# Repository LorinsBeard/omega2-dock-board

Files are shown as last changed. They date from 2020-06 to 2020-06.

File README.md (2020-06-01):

# Omega2 Dock board

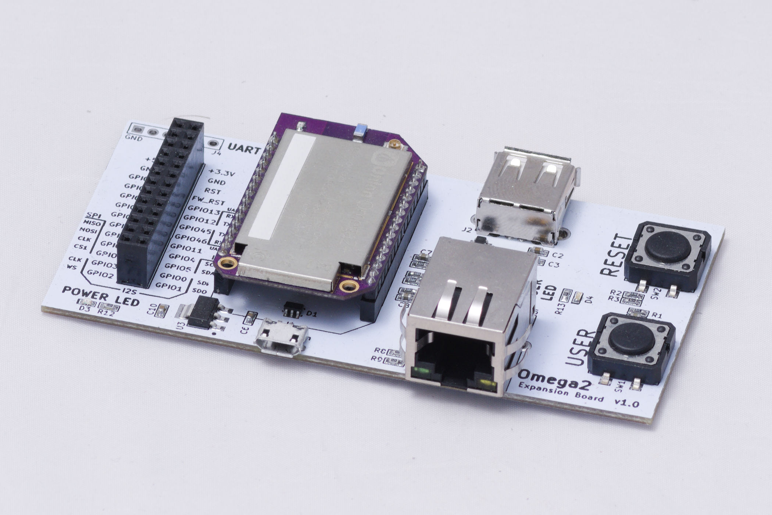
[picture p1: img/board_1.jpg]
Omega board photo 1


Inspired by [Omega dock\new](https://github.com/5N44P/omega-dock-new) board.

## Overview

This is yet another dock for Onion Omega2/Omega2+ single board computers. 
Main board features:

* Ethernet socket
* USB type A Host
* Micro USB power and UART
* Expansion pins
* User Button and LED

## BOM

BOM is also available in CSV format.

| Reference | Quantity | Description | MPN | Manufacturer | Datasheet |
|---|---:|---|-----|---|---|
| C10 C2  | 2 | CAP CER 10UF 6.3V X5R 0603 | CL10A106MQ8NNNC | Samsung Electro-Mechanics | [link](http://www.samsungsem.com/kr/support/product-search/mlcc/__icsFiles/afieldfile/2018/06/20/CL10A106MQ8NNNC.pdf) |
| C4 C5  | 2 | CAP CER 22pF 50V NPO 0603 | CL10C220JB8NNN | Samsung Electro-Mechanics | [link](www.samsungsem.com/global/front/downloadcms.do?path=%2F%2Fglobal%2F%2Fsupport%2F%2Fproduct-search%2F%2Fmlcc%2F%2F__icsFiles%2F%2Fafieldfile%2F%2F2016%2F%2F08%2F%2F18&fileName=S_CL10C220JB8NNNL.pdf) |
| C6 C8 C7 C1 C3  | 5 | CAP CER 0.1UF 50V X7R 0603 | CL10B104KB8NNNC | Samsung Electro-Mechanics | [link](http://www.samsungsem.com/kr/support/product-search/mlcc/__icsFiles/afieldfile/2018/07/24/CL10B104KB8NNNC.pdf) |
| C9  | 1 | CAP CER 1UF 16V X7R 0603 | CL10B105KO8NNNC | Samsung Electro-Mechanics | [link](http://www.samsungsem.com/kr/support/product-search/mlcc/__icsFiles/afieldfile/2019/06/18/CL10B105KO8NNNC-19.pdf) |
| D2 D1  | 2 | TVS DIODE 5.25V 17V SOT23-6 | USBLC6-2SC6 | STMicroelectronics | [link](http://www.st.com/content/ccc/resource/technical/document/datasheet/06/1d/48/9c/6c/20/4a/b2/CD00050750.pdf/files/CD00050750.pdf/jcr:content/translations/en.CD0005075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) |
| D3 D4  | 2 | LED Yellow Green 0603 30mA | FYLS-0603GD | FORYARD OPTOELECTRONICS | [link](http://www.foryard-led.ru/pdf/fyls-0603gd.pdf) |
| F1  | 1 | PTC RESET FUSE 6V 1.1A 1206 | MF-NSMF110-2 | Bourns | [link](https://www.bourns.com/docs/Product-Datasheets/mfnsmf.pdf) |
| J1  | 1 | CONN RCPT USB2.0 MICRO B SMD R/A | 10118194-0001LF | Amphenol ICC (FCI) | [link](http://www.amphenol-icc.com/media/wysiwyg/files/drawing/10118194.pdf) |
| J2  | 1 | CONN RCPT USB2.0 TYPEA 4POS R/A | KLS1-181A-W | KLS | [link](http://www.klsele.com/admin/product_upload/20190917081512KLS1-1811%20A%20Female%20Dip%2090%20USB%20Connector%202.jpg.pdf) |
| J3  | 1 | CONN F HEADER 26POS 2.54mm | ZL262-26DG | CONNFLY | [link](http://www.kosmodrom.com.ua/pdf/zl262-dg.pdf) |
| J4  | 1 | CONN M HEADER 6 POS 2.54mm | ZL201-06G | CONNFLY | [link](http://www.kosmodrom.com.ua/pdf/zl201.pdf) |
| J5  | 1 | RJ45 connector with transformer | KLS12-TL002R-1*1-G/Y-1-03 | KLS | [link](http://www.klsele.com/admin/product_upload/20170620132005KLS12-TL002-1X1.pdf) |
| R1 R3  | 2 | SMD RES 0603 10 kOhm 100mW 50V | RC0603FR-10KR | Hitano | [link](https://www.rcscomponents.kiev.ua/datasheets/komechip-eesistor-datasheet.pdf) |
| R11 R7 R6 R10  | 4 | SMD RES 0603 49.9 Ohm 100mW 50V | RC0603FR-49R9 | Hitano | [link](https://www.rcscomponents.kiev.ua/datasheets/rc_series_hitano-datasheet.pdf) |
| R12 R4 R5 R8 R9 R2 R13  | 7 | SMD RES 0603 470 Ohm 100mW 50V | RC0603JR-470R | Hitano | [link](https://www.rcscomponents.kiev.ua/datasheets/rc_series_hitano-datasheet.pdf) |
| SW2 SW1  | 2 | SWITCH TACTILE SPST-NO 0.05A 12V | TACTM-24N-F | NINIGI | [link](https://en.ninigi.com/product/tactm-24n-f/pdf) |
| U1  | 1 | USB UART CONVERTER 16SOIC | CH340G | WCH | [link](www.datasheet5.com/pdf-local-2195953) |
| U2  | 1 | SBC  | Omega2 | Onion | [link](https://docs.onion.io/omega2-docs/omega2p.html) |
| U3  | 1 | IC REG LINEAR 3.3V 800MA SOT223  | LD1117S33TR | STMicroelectronics | [link](https://www.st.com/content/ccc/resource/technical/document/datasheet/99/3b/7d/91/91/51/4b/be/CD00000544.pdf/files/CD00000544.pdf/jcr:content/translations/en.CD000005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) |
| Y1  | 1 | Quartz Crystal SMD 12.0 MHz | 12.88662 | GEYER | [link](https://www.geyer-electronic.com/fileadmin/user_upload/frequenz/quartz/KX-7/GEYER-KX-7.pdf) |

Note:

I have bought a KLS Ethernet connector for **J5** but used a footprint for [Amphenol ICC RJMG1BD3B8K1ANR](https://www.digikey.com/product-detail/en/amphenol-icc-commercial-products/RJMG1BD3B8K1ANR/RJMG1BD3B8K1ANR-ND/5359794) connector. There is just one difference - **reversed pinout** for Yellow LED. 

Also, I have bought a KLS USB A connector for **J2** and used an [Amphenol ICC UE27AC54100](https://www.digikey.com/product-detail/en/amphenol-icc-commercial-products/UE27AC54100/UE27AC54100-ND) footprint, but they are similar, though.

## Schematic & PCB

Designed using **KiCAD**. Also, I have take some parts from [Digi-Key Kicad library](https://www.digikey.com/en/resources/design-tools/kicad). 

The library with footprints is available at the project directory [omega-dock](./omega-dock).

Board has user **Button** at **GPIO11** and **LED** at **GPIO17**. To able these ones just solder bridges **SB1** and **SB4**.

Also, to able Ethernet LEDs solder bridges **SB2** and **SB3**.

## Known bugs

I have realized that there is no fuse for a USB power socket and it may cause damage to the USB port on your PC. So, it recommends using USB 3.0 and higher.

## Other photos

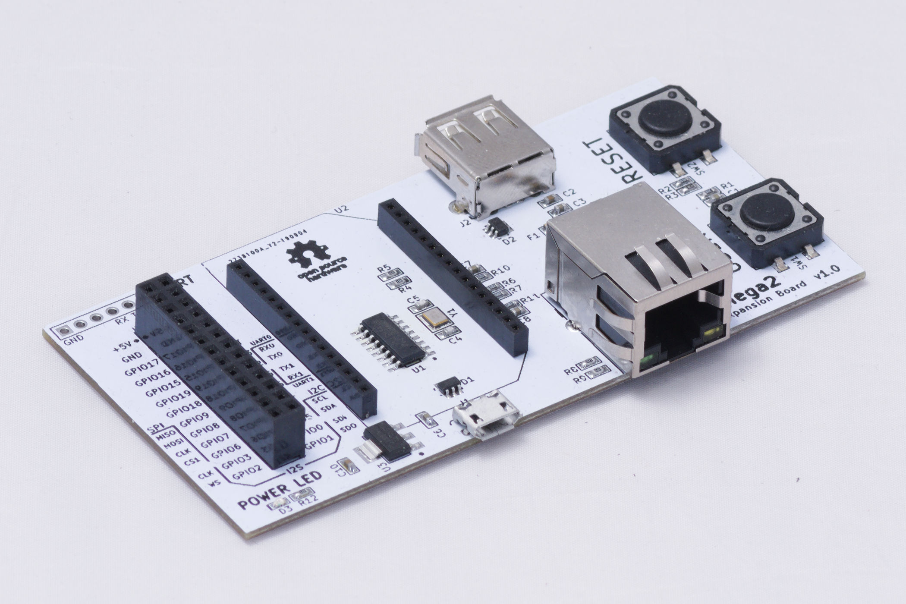
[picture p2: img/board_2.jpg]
Omega board photo 2

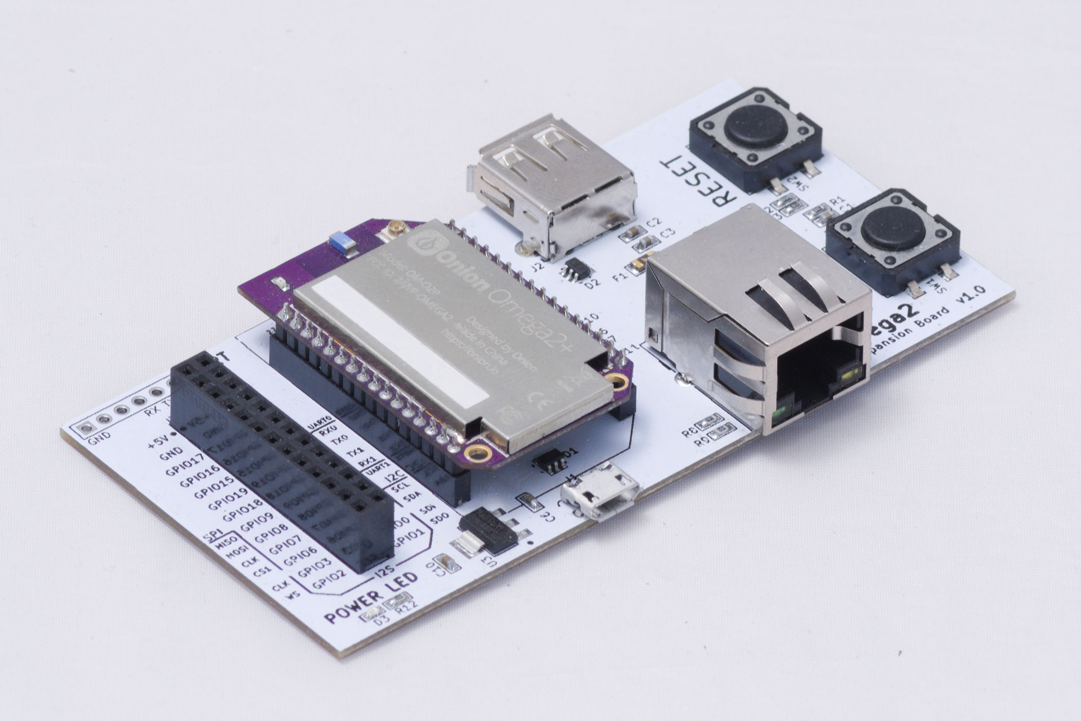
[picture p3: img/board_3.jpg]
Omega board photo 3


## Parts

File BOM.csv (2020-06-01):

Reference | Quantity | Description | MPN | Manufacturer | Datasheet
C10 C2 | 2 | CAP CER 10UF 6.3V X5R 0603 | CL10A106MQ8NNNC | Samsung Electro-Mechanics | http://www.samsungsem.com/kr/support/product-search/mlcc/__icsFiles/afieldfile/2018/06/20/CL10A106MQ8NNNC.pdf
C4 C5 | 2 | CAP CER 22pF 50V NPO 0603 | CL10C220JB8NNN | Samsung Electro-Mechanics | www.samsungsem.com/global/front/downloadcms.do?fileName=S_CL10C220JB8NNNL.pdf
C6 C8 C7 C1 C3 | 5 | CAP CER 0.1UF 50V X7R 0603 | CL10B104KB8NNNC | Samsung Electro-Mechanics | http://www.samsungsem.com/kr/support/product-search/mlcc/__icsFiles/afieldfile/2018/07/24/CL10B104KB8NNNC.pdf
C9 | 1 | CAP CER 1UF 16V X7R 0603 | CL10B105KO8NNNC | Samsung Electro-Mechanics | http://www.samsungsem.com/kr/support/product-search/mlcc/__icsFiles/afieldfile/2019/06/18/CL10B105KO8NNNC-19.pdf
D2 D1 | 2 | TVS DIODE 5.25V 17V SOT23-6 | USBLC6-2SC6 | STMicroelectronics | http://www.st.com/content/ccc/resource/technical/document/datasheet/06/1d/48/9c/6c/20/4a/b2/CD00050750.pdf/files/CD00050750.pdf/jcr:content/translations/en.CD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
D3 D4 | 2 | LED Yellow Green 0603 30mA | FYLS-0603GD | FORYARD OPTOELECTRONICS | http://www.foryard-led.ru/pdf/fyls-0603gd.pdf
F1 | 1 | PTC RESET FUSE 6V 1.1A 1206 | MF-NSMF110-2 | Bourns | https://www.bourns.com/docs/Product-Datasheets/mfnsmf.pdf
J1 | 1 | CONN RCPT USB2.0 MICRO B SMD R/A | 10118194-0001LF | Amphenol ICC (FCI) | http://www.amphenol-icc.com/media/wysiwyg/files/drawing/10118194.pdf
J2 | 1 | CONN RCPT USB2.0 TYPEA 4POS R/A | KLS1-181A-W | KLS | http://www.klsele.com/admin/product_upload/20190917081512KLS1-1811%20A%20Female%20Dip%2090%20USB%20Connector%202.jpg.pdf
J3 | 1 | CONN F HEADER 26POS 2.54mm | ZL262-26DG | CONNFLY | http://www.kosmodrom.com.ua/pdf/zl262-dg.pdf
J4 | 1 | CONN M HEADER 6 POS 2.54mm | ZL201-06G | CONNFLY | http://www.kosmodrom.com.ua/pdf/zl201.pdf
J5 | 1 | RJ45 connector with transformer | KLS12-TL002R-1*1-G/Y-1-03 | KLS | http://www.klsele.com/admin/product_upload/20170620132005KLS12-TL002-1X1.pdf
R1 R3 | 2 | SMD RES 0603 10 kOhm 100mW 50V | RC0603FR-10KR | Hitano | https://www.rcscomponents.kiev.ua/datasheets/komechip-eesistor-datasheet.pdf
R11 R7 R6 R10 | 4 | SMD RES 0603 49.9 Ohm 100mW 50V | RC0603FR-49R9 | Hitano | https://www.rcscomponents.kiev.ua/datasheets/rc_series_hitano-datasheet.pdf
R12 R4 R5 R8 R9 R2 R13 | 7 | SMD RES 0603 470 Ohm 100mW 50V | RC0603JR-470R | Hitano | https://www.rcscomponents.kiev.ua/datasheets/rc_series_hitano-datasheet.pdf
SW2 SW1 | 2 | SWITCH TACTILE SPST-NO 0.05A 12V | TACTM-24N-F | NINIGI | https://en.ninigi.com/product/tactm-24n-f/pdf
U1 | 1 | USB UART CONVERTER 16SOIC | CH340G | WCH | www.datasheet5.com/pdf-local-2195953
U2 | 1 | SBC | Omega2 | Onion | https://docs.onion.io/omega2-docs/omega2p.html
U3 | 1 | IC REG LINEAR 3.3V 800MA SOT223 | LD1117S33TR | STMicroelectronics | https://www.st.com/content/ccc/resource/technical/document/datasheet/99/3b/7d/91/91/51/4b/be/CD00000544.pdf/files/CD00000544.pdf/jcr:content/translations/en.C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
Y1 | 1 | Quartz Crystal SMD 12.0 MHz | 12.88662 | GEYER | https://www.geyer-electronic.com/fileadmin/user_upload/frequenz/quartz/KX-7/GEYER-KX-7.pdf

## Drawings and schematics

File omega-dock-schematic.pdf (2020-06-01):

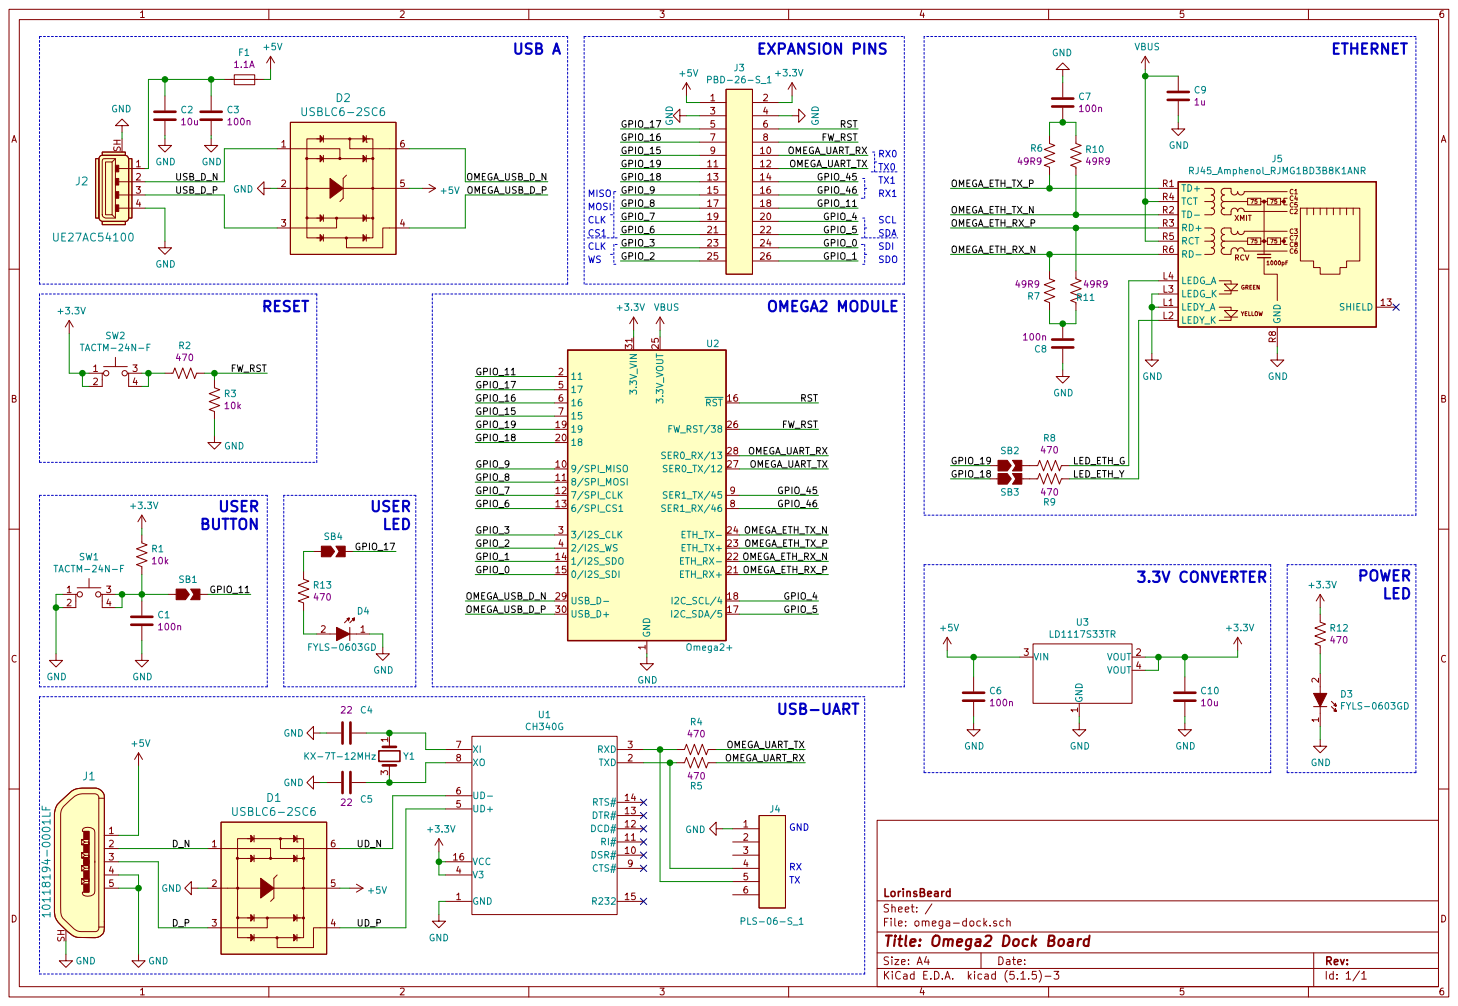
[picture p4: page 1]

File: omega-dock.sch Sheet: / LorinsBeard

Id: 1/1 Title: Omega2 Dock Board

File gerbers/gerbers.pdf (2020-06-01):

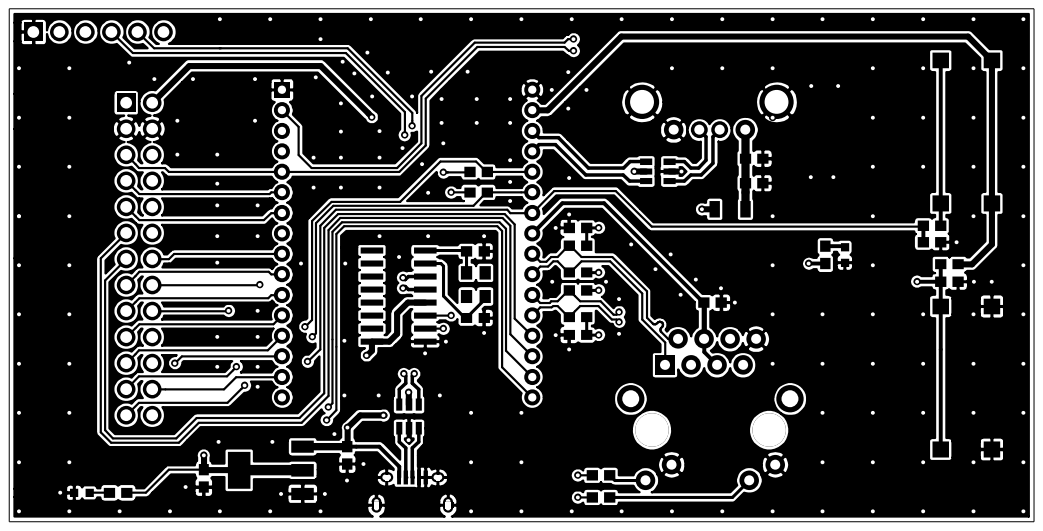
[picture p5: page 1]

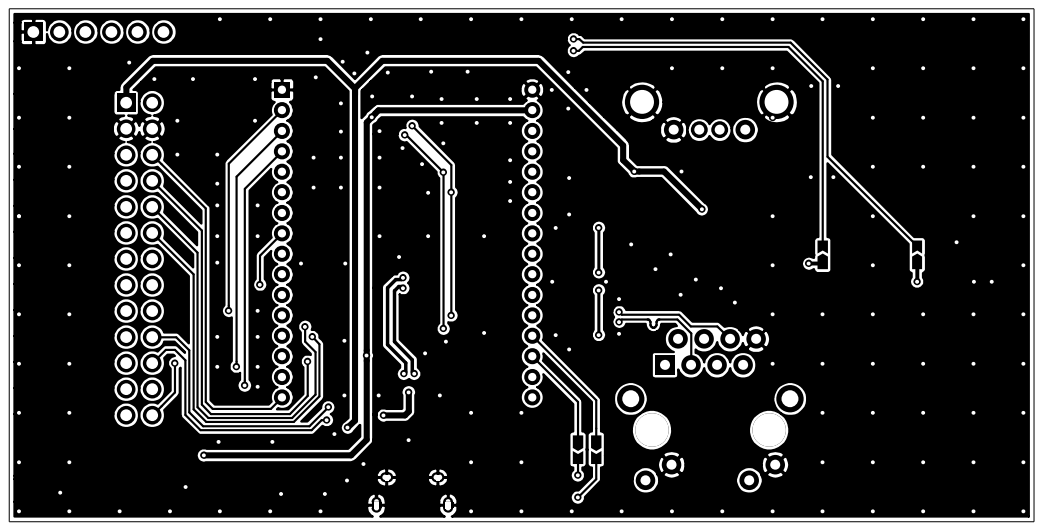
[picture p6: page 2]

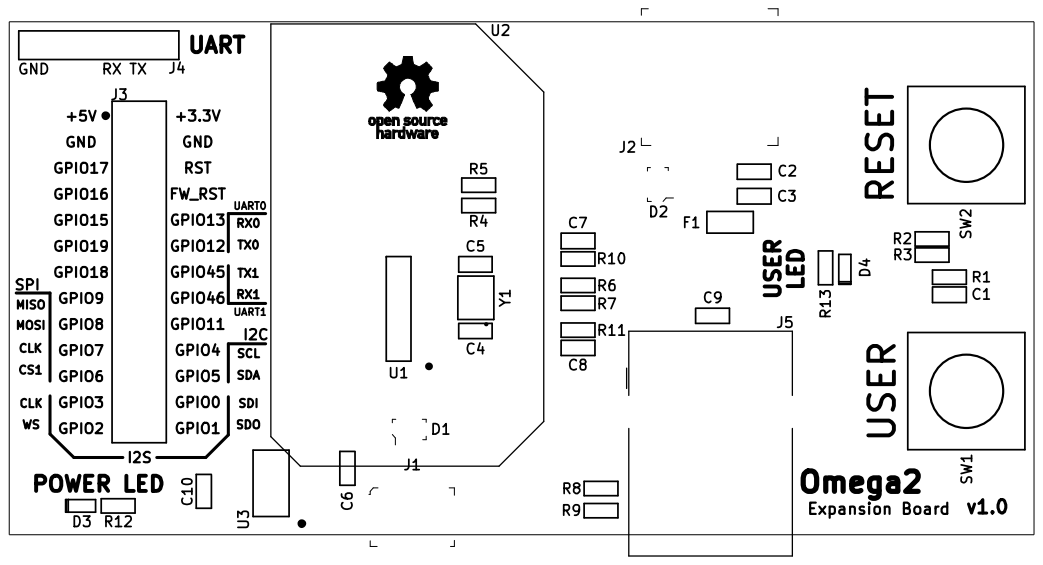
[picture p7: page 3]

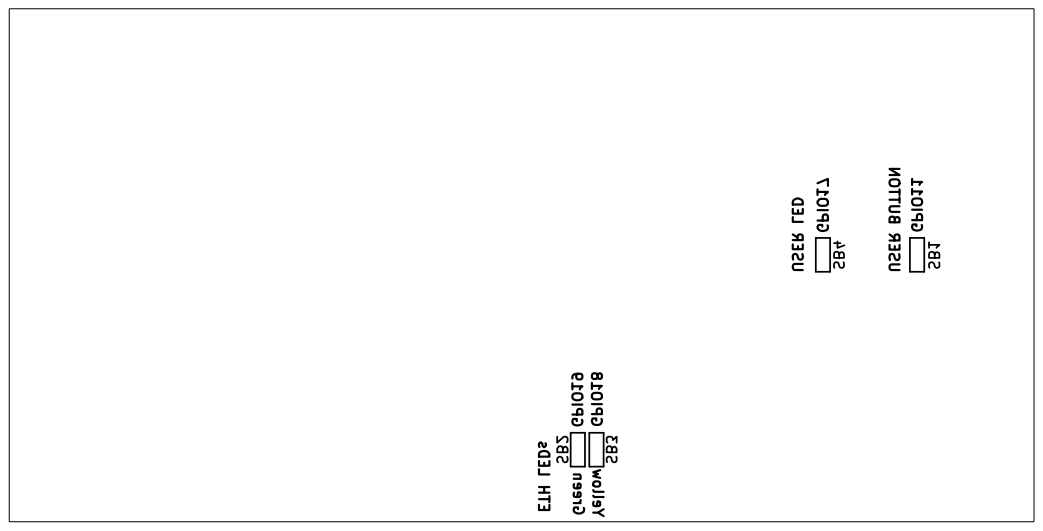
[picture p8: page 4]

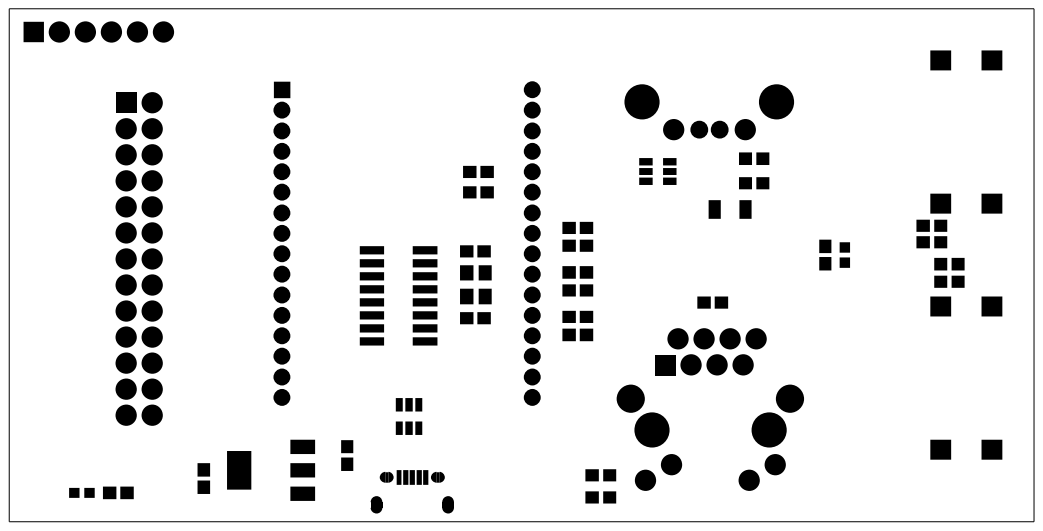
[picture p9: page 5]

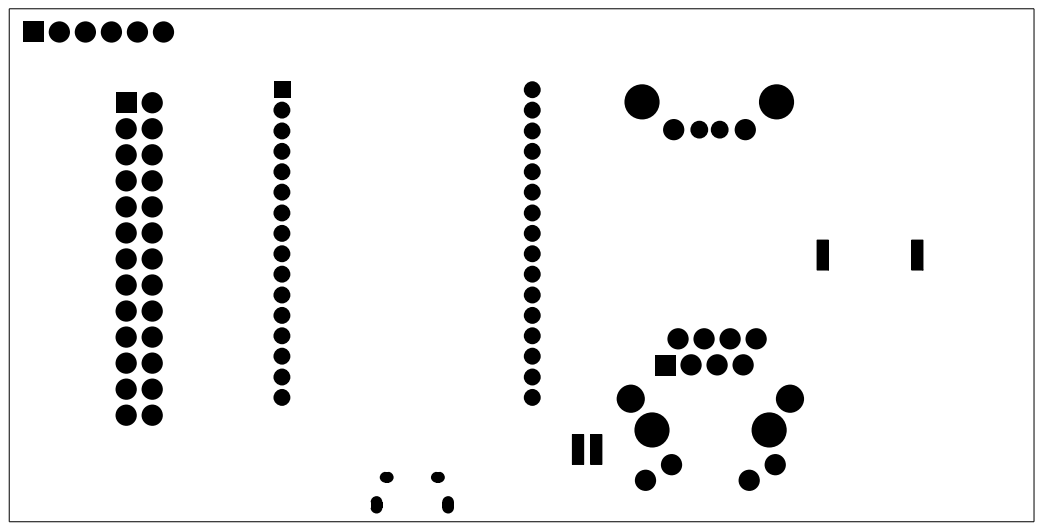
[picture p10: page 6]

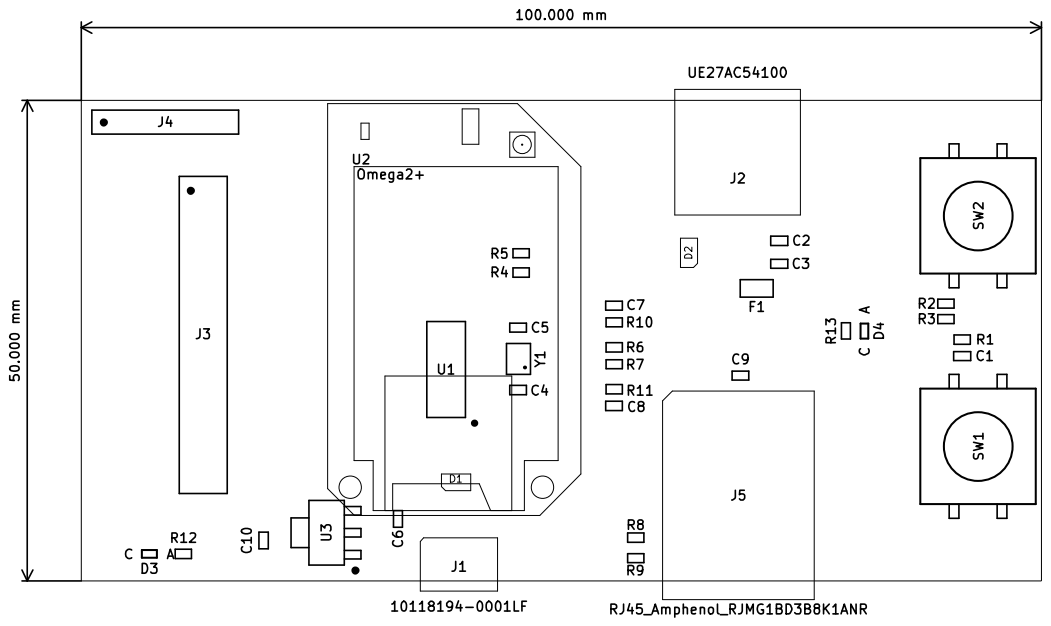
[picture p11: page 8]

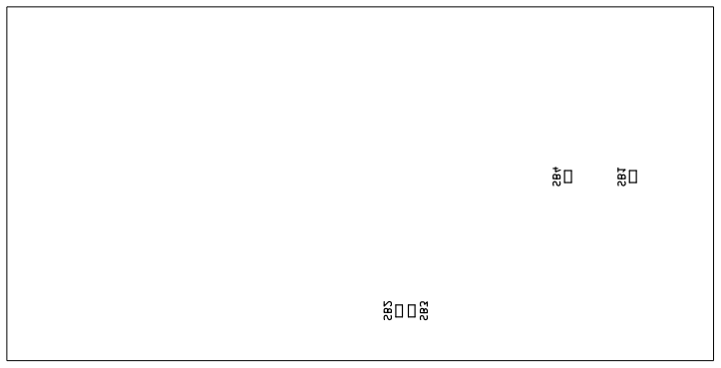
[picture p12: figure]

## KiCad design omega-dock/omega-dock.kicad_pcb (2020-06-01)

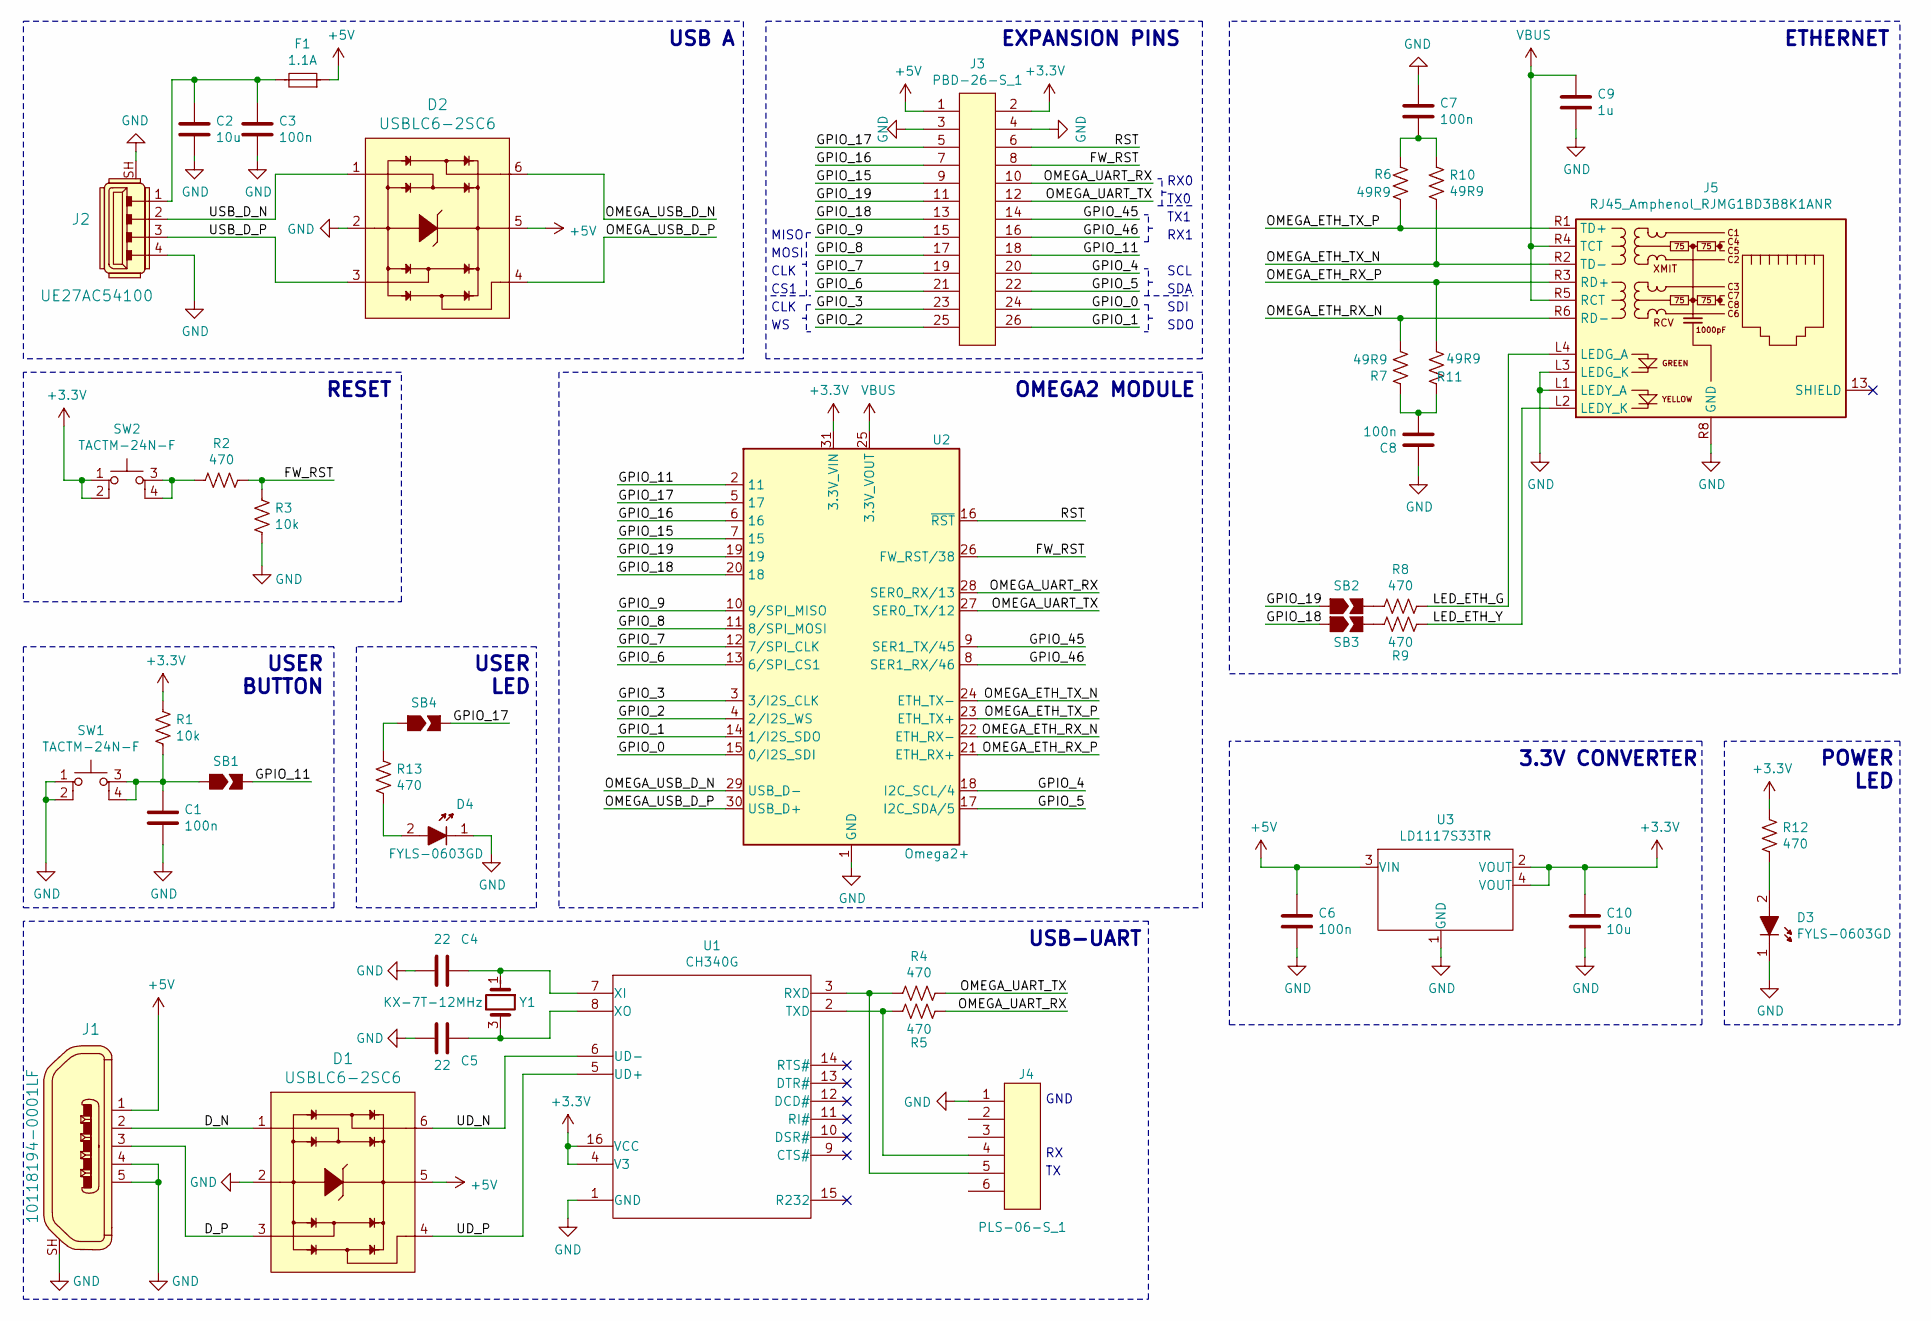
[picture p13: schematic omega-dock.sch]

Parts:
C1, C3, C6, C7, C8: 100n_0603_1; C_0603; MPN CL10B104KB8NNNC
C2, C10: 10u_0603_1; C_0603; MPN CL10A106MQ8NNNC
C4, C5: 22p_0603_1; C_0603; MPN CL10C220JB8NNN
C9: 1u_0603_1; C_0603; MPN CL10B105KO8NNNC
D1, D2: USBLC6-2SC6; SOT23-6L; MPN USBLC6-2SC6; Digi-Key_PN 497-5235-1-ND
D3, D4: FYLS-0603GD; LED_0603_1; MPN FYLS-0603GD
F1: MF-NSMF110; Fuse_BOURNS_MF-NSMF; MPN MF-NSMF110-2
J1: 10118194-0001LF; USB_Micro_B_Female_10118194-0001LF; MPN 10118194-0001LF; Digi-Key_PN 609-4618-1-ND
J2: UE27AC54100; USB_A_Female_UE27AC54100; MPN UE27AC54100; Digi-Key_PN UE27AC54100-ND
J3: PBD-26-S_1; MPN ZL262-26DG
J4: PLS-06-S_1; MPN ZL201-06G
J5: RJ45_Amphenol_RJMG1BD3B8K1ANR
R1, R3: 10K_0603_1; R_0603; MPN RC0603FR-10KR
R2, R4, R5, R8, R9, R12, R13: 470R_0603_1; R_0603; MPN RC0603JR-470R
R6, R7, R10, R11: 49R9_0603_1; R_0603; MPN RC0603FR-49R9
SB1, SB2, SB3, SB4: SB_0603_1; SB_0603_TRIANGLE
SW1, SW2: TACTM-24N-F; PUSHB_TL3300DF260Q; MPN TACTM-24N-F
U1: CH340G; SOIC-16; MPN CH340G
U2: Omega2+; Onion_Omega2+
U3: LD1117S33TR; SOT-223; MPN LD1117S33TR
Y1: KX-7T-12MHz; KX-7T; MPN 12.88662

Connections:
+3V3: C10.1, J3.2, R1.1, R12.1, SW2.1, SW2.2, U1.4 (V3), U1.16 (VCC), U2.31 (3.3V_VIN), U3.2 (VOUT), U3.4 (VOUT)
+5V: C6.1, D1.5, D2.5, F1.1, J1.1, J3.1, U3.3 (VIN)
/D_N: D1.1, J1.2
/D_P: D1.3, J1.3
/FW_RST: J3.8, R2.1, R3.1, U2.26 (FW_RST/38)
/GPIO_0: J3.24, U2.15 (0/I2S_SDI)
/GPIO_1: J3.26, U2.14 (1/I2S_SDO)
/GPIO_2: J3.25, U2.4 (2/I2S_WS)
/GPIO_3: J3.23, U2.3 (3/I2S_CLK)
/GPIO_4: J3.20, U2.18 (I2C_SCL/4)
/GPIO_5: J3.22, U2.17 (I2C_SDA/5)
/GPIO_6: J3.21, U2.13 (6/SPI_CS1)
/GPIO_7: J3.19, U2.12 (7/SPI_CLK)
/GPIO_8: J3.17, U2.11 (8/SPI_MOSI)
/GPIO_9: J3.15, U2.10 (9/SPI_MISO)
/GPIO_11: J3.18, SB1.2, U2.2 (11)
/GPIO_15: J3.9, U2.7 (15)
/GPIO_16: J3.7, U2.6 (16)
/GPIO_17: J3.5, SB4.2, U2.5 (17)
/GPIO_18: J3.13, SB3.1, U2.20 (18)
/GPIO_19: J3.11, SB2.1, U2.19
/GPIO_45: J3.14, U2.9 (SER1_TX/45)
/GPIO_46: J3.16, U2.8 (SER1_RX/46)
/LED_ETH_G: J5.L4 (LEDG_A), R8.1
/LED_ETH_Y: J5.L2 (LEDY_K), R9.2
/OMEGA_ETH_RX_N: J5.R6 (RD-), R7.2, U2.22 (ETH_RX-)
/OMEGA_ETH_RX_P: J5.R3 (RD+), R11.1, U2.21 (ETH_RX+)
/OMEGA_ETH_TX_N: J5.R2 (TD-), R10.2, U2.24 (ETH_TX-)
/OMEGA_ETH_TX_P: J5.R1 (TD+), R6.1, U2.23 (ETH_TX+)
/OMEGA_UART_RX: J3.10, R5.2, U2.28 (SER0_RX/13)
/OMEGA_UART_TX: J3.12, R4.1, U2.27 (SER0_TX/12)
/OMEGA_USB_D_N: D2.6, U2.29 (USB_D-)
/OMEGA_USB_D_P: D2.4, U2.30 (USB_D+)
/RST: J3.6, U2.16 (~RST)
/UD_N: D1.6, U1.6 (UD-)
/UD_P: D1.4, U1.5 (UD+)
/USB_D_N: D2.1, J2.2
/USB_D_P: D2.3, J2.3
GND: C1.2, C2.2, C3.2, C4.2, C5.2, C6.2, C7.1, C8.1, C9.2, C10.2, D1.2, D2.2, D3.1, D4.1, J1.4, J1.5, J1.SH, J2.4, J2.SH, J3.3, J3.4, J4.1, J5.L1 (LEDY_A), J5.L3 (LEDG_K), J5.R8 (GND), R3.2, SW1.1, SW1.2, U1.1 (GND), U2.1 (GND), U2.32 (GND), U3.1 (GND)
unnamed: C1.1, R1.2, SB1.1, SW1.3, SW1.4
unnamed: C2.1, C3.1, F1.2, J2.1
unnamed: C4.1, U1.7 (XI), Y1.1
unnamed: C5.1, U1.8 (XO), Y1.3
unnamed: C7.2, R6.2, R10.1
unnamed: C8.2, R7.1, R11.2
unnamed: D3.2, R12.2
unnamed: D4.2, R13.2
unnamed: J4.4, R5.1, U1.2 (TXD)
unnamed: J4.5, R4.2, U1.3 (RXD)
unnamed: R2.2, SW2.3, SW2.4
unnamed: R8.2, SB2.2
unnamed: R9.1, SB3.2
unnamed: R13.1, SB4.1
VBUS: C9.1, J5.R4 (TCT), J5.R5 (RCT), U2.25 (3.3V_VOUT)

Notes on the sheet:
RESET
USER BUTTON
OMEGA2 MODULE
USB A
EXPANSION PINS
ETHERNET
USB-UART
3.3V CONVERTER
POWER LED
GND
CLK
MOSI
MISO
CS1
SDO
SDI
SDA
SCL
TX0
RX0
RX1
TX1
USER LED

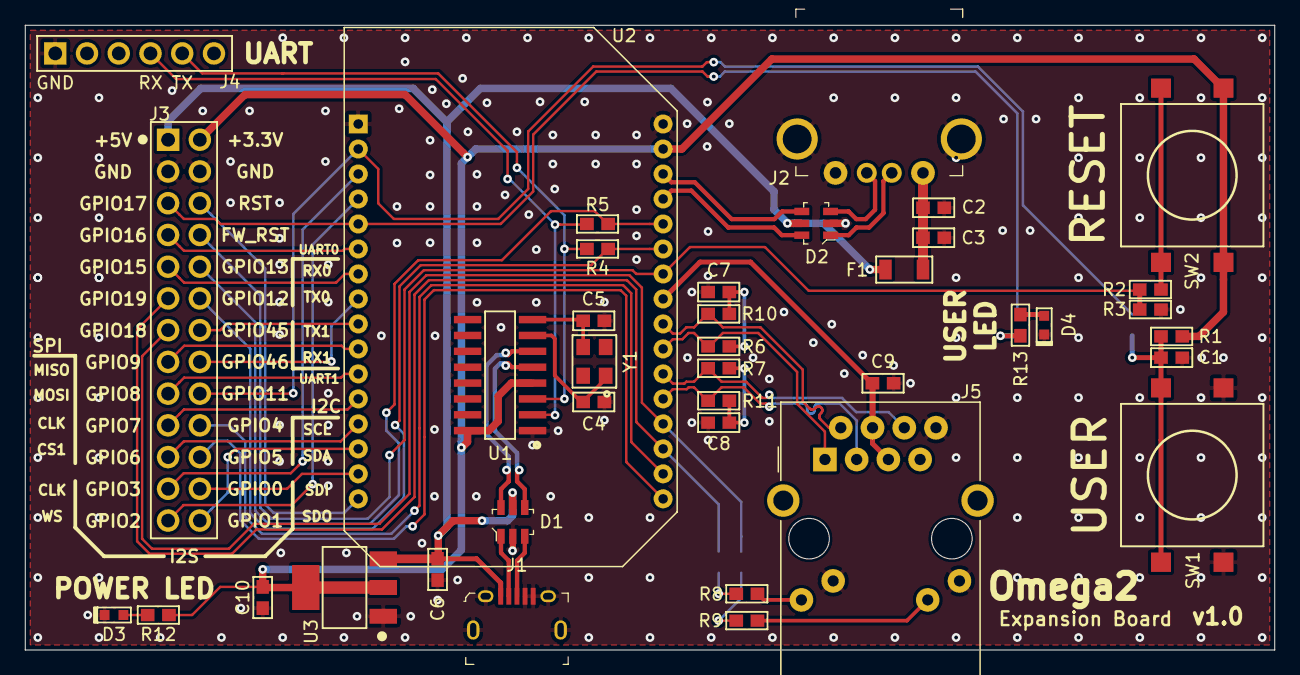
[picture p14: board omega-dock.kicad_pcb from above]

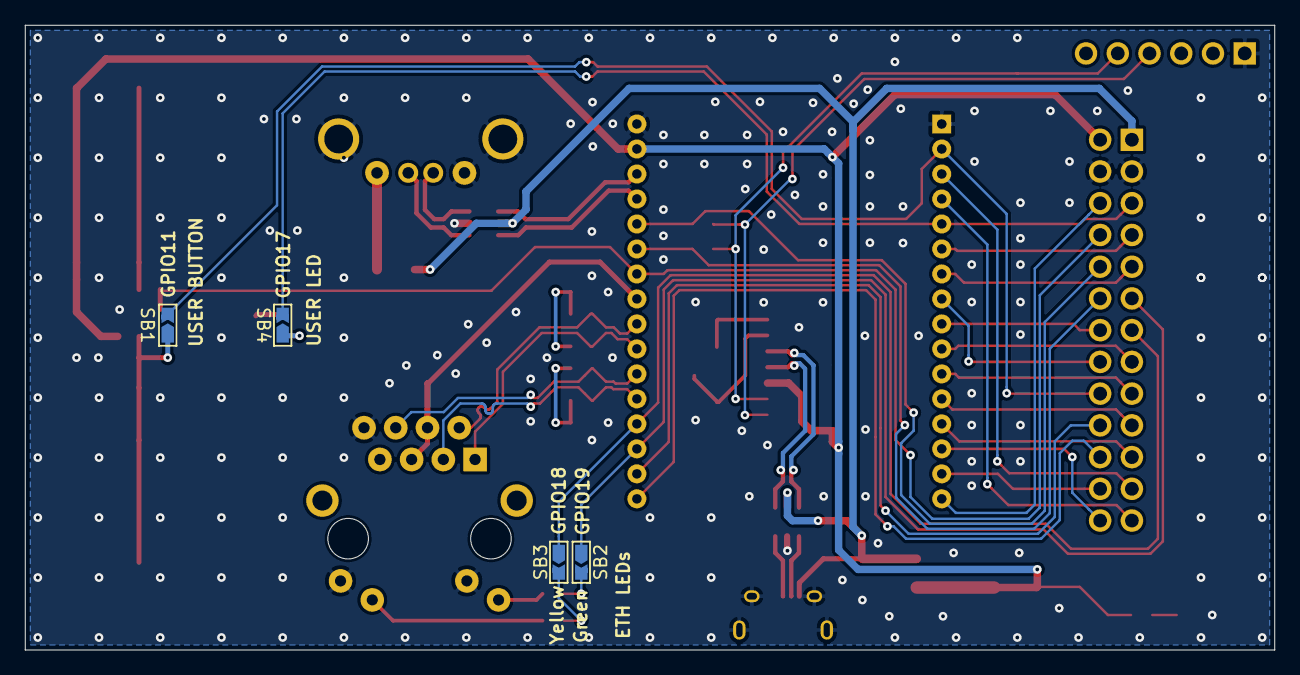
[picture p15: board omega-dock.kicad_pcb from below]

Board: 2 copper layers, 100.0 x 50.0 mm, 43 parts (4 on the bottom side), 54 nets.
